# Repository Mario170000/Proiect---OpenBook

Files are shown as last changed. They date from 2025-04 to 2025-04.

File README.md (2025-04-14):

# Proiect---OpenBook
Proiectarea unui e-book reader open book

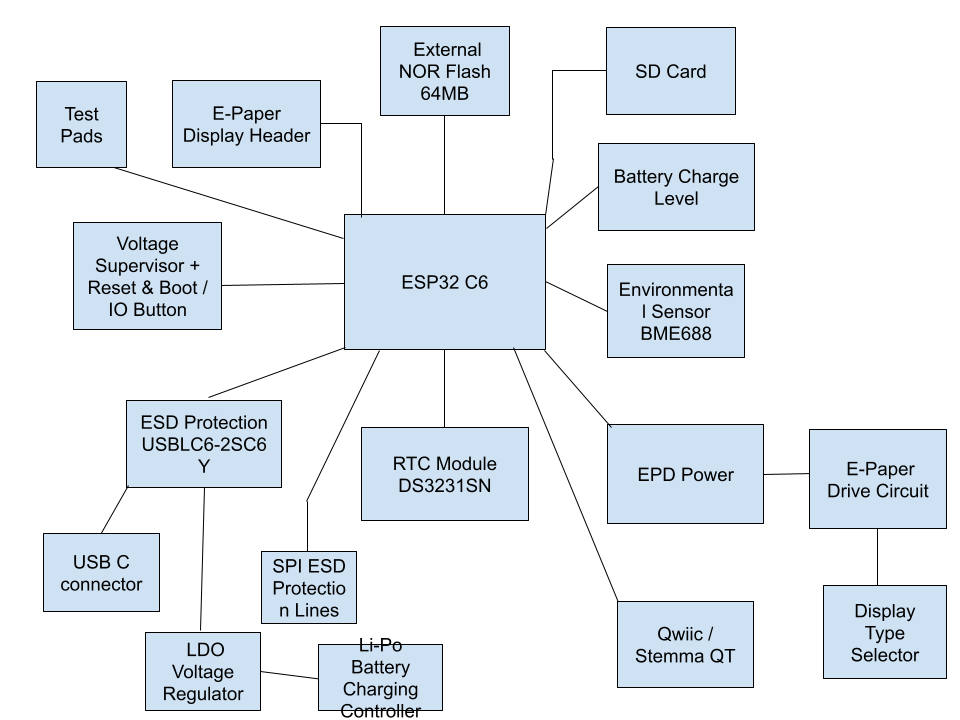
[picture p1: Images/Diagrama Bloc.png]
Diagrama bloc


BOM:

| Qty | Value | Device | Parts | Description | WHERE_TO_BUY | DATASHEET |
|-----|---|---|---|---|---|---|
| 1 | | ADAFRUIT_LEDCHIP-LED0603 | CHG_LED | LED | [link](https://ro.mouser.com/ProductDetail/BJB/35.116.1007-001-01?qs=iLKYxzqNS76jqQb6thkyzg%3D%3D) | [link](https://ro.mouser.com/datasheet/2/904/BJBDE_6680739_v3_Datasheet_35_116_1007_85_Optics4x-3193726.pdf) |
| 3 | | EAGLE-LTSPICE_CC0402 | C4_USB, C5_USB, C17 | CAPACITOR, European symbol | [link](https://ro.mouser.com/ProductDetail/YAGEO/CC0402KRX7R5BB474?qs=tS%2FAHvPQ%2F56tORtAcxAOhQ%3D%3D) | [link](https://ro.mouser.com/datasheet/2/447/UPY_GPHC_X7R_6_3V_to_250V_24-3441574.pdf) |
| 1 | | SJ | SJ1 | SMD solder JUMPER | [link](https://ro.mouser.com/ProductDetail/Amphenol-FCI/71363-302LF?qs=QPQicS5vByJvpVjU0oRgsQ%3D%3D) | [link](https://cdn.amphenol-cs.com/media/wysiwyg/files/documentation/datasheet/boardwiretoboard/bwb_dubox_shunts.pdf) |
| 1 | 0.1uF/50V | EAGLE-LTSPICE_CC0402 | EPD_C5 | CAPACITOR, European symbol | [link](https://ro.mouser.com/ProductDetail/YAGEO/CC0402JRX7R8BB104?qs=tS%2FAHvPQ%2F56C6Jcuby2Lxg%3D%3D) | [link](https://ro.mouser.com/datasheet/2/447/UPY_GPHC_X7R_6_3V_to_250V_24-3441574.pdf) |
| 1 | 0.47 | ESP32_WROVER_EAGLE-LTSPICE_RR0402 | R4 | RESISTOR, European symbol | [link](https://ro.mouser.com/ProductDetail/Vishay/PFRR0402Y2101WBT?qs=iLKYxzqNS75ICTUqzuuuLQ%3D%3D) | [link](https://www.vishay.com/doc?53046) |
| 1 | 100K | ESP32_WROVER_EAGLE-LTSPICE_RR0402 | R1_PWRUSB | RESISTOR, European symbol | [link](https://ro.mouser.com/ProductDetail/Vishay/PFRR0402Y1003WBT?qs=iLKYxzqNS76UwFIGpGXUcw%3D%3D) | [link](https://www.vishay.com/doc?53046) |
| 7 | 100nF | EAGLE-LTSPICE_CC0402 | C1, C2, C6, C8, C9, C10, C_DELAY | CAPACITOR, European symbol | [link](https://ro.mouser.com/ProductDetail/YAGEO/CC0402KRX7R5BB474?qs=tS%2FAHvPQ%2F56tORtAcxAOhQ%3D%3D) | [link](https://ro.mouser.com/datasheet/2/447/UPY_GPHC_X7R_6_3V_to_250V_24-3441574.pdf) |
| 1 | 100uF | RCL_CPOL-EUCT3528 | C3 | POLARIZED CAPACITOR, European symbol | [link](https://ro.mouser.com/ProductDetail/Panasonic/EEU-FS1K101L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) | [link](https://www.mouser.com/catalog/specsheets/Panasonic_08082018_Capacitor%20Radial%20Leaded%20Lytic%20(EEU-FS)%20020118.pdf) |
| 12  | 10K | ESP32_WROVER_EAGLE-LTSPICE_RR0402 | R1_PINH, R1_PINH1, R2-PINH1, R2_PINH, R3, R5, R6, R7, R8, R9, R10, R_CL1 | RESISTOR, European symbol | [link](https://ro.mouser.com/ProductDetail/Vishay/PFRR0402Y1002WBT?qs=iLKYxzqNS75QPApzdnOraw%3D%3D) | [link](https://www.vishay.com/doc?53046) |
| 3 | 10k | ESP32_WROVER_EAGLE-LTSPICE_RR0402 | R_BOOT, R_CHANGE, R_RESET | RESISTOR, European symbol | [link](https://ro.mouser.com/ProductDetail/Vishay/PFRR0402Y1002WBT?qs=iLKYxzqNS75QPApzdnOraw%3D%3D) | [link](https://www.vishay.com/doc?53046) |
| 1 | 10uF | EAGLE-LTSPICE_CC0402 | C7 | CAPACITOR, European symbol | [link](https://ro.mouser.com/ProductDetail/YAGEO/CC0402MRX5R4BB106?qs=tS%2FAHvPQ%2F561gTjBOiVihQ%3D%3D) | [link](https://ro.mouser.com/datasheet/2/447/upy_gphc_x5r_4v_to_50v-3461255.pdf) |
| 1 | 112A-TAAR-R03_ATTEND | 112A-TAAR-R03_ATTEND | J4 | Micro SD Card Socket, Push-Push Type, Top Mount, SMT, H=1.83mm, 10u | [link](https://ro.mouser.com/ProductDetail/Swissbit/SFSD256GL2AM1TO-E-8H-231-STD?qs=%252BXxaIXUDbq3EiR9fdqsT0g%3D%3D) | [link](https://ro.mouser.com/datasheet/2/615/Swissbit_02_03_2025_S_50_data_sheet-3561244.pdf) |
| 1 | 15 | ESP32_WROVER_EAGLE-LTSPICE_RR0402 | R_CAPACITOR | RESISTOR, European symbol | [link](https://ro.mouser.com/ProductDetail/Vishay/PFRR0402Y1002WBT?qs=iLKYxzqNS75QPApzdnOraw%3D%3D) | [link](https://www.vishay.com/doc?53046) |
| 1 | 1uF | EAGLE-LTSPICE_CC0402 | C5 | CAPACITOR, European symbol | [link](https://ro.mouser.com/ProductDetail/YAGEO/CC0402KPX7R9BB332?qs=tS%2FAHvPQ%2F56Ev%2FR70%252BDkow%3D%3D) | [link](https://ro.mouser.com/datasheet/2/447/UPY_GPHC_X7R_6_3V_to_250V_24-3441574.pdf) |
| 9 | 1uF/50V | EAGLE-LTSPICE_CC0402 | EPD_C1, EPD_C2, EPD_C6, EPD_C7, EPD_C8, EPD_C9, EPD_C10, EPD_C11, EPD_C12 | CAPACITOR, European symbol | [link](https://ro.mouser.com/ProductDetail/YAGEO/CC0402KPX7R9BB332?qs=tS%2FAHvPQ%2F56Ev%2FR70%252BDkow%3D%3D) | [link](https://ro.mouser.com/datasheet/2/447/UPY_GPHC_X7R_6_3V_to_250V_24-3441574.pdf) |
| 1 | 2.2 | ESP32_WROVER_EAGLE-LTSPICE_RR0402 | R2 | RESISTOR, European symbol | [link](https://ro.mouser.com/ProductDetail/Vishay/PFRR0402Y2201WBT?qs=iLKYxzqNS76BFrJRYiyDBw%3D%3D) | [link](https://www.vishay.com/doc?53046) |
| 1 | 200 | ESP32_WROVER_EAGLE-LTSPICE_RR0402 | R1_BAT | RESISTOR, European symbol | [link](https://ro.mouser.com/ProductDetail/Vishay/PFRR0402Y2101WBT?qs=iLKYxzqNS75ICTUqzuuuLQ%3D%3D) | [link](https://www.vishay.com/doc?53046) |
| 2 | 20V/4.2A/52mO/1.4W | ESP32_WROVER_SPARKFUN-DISCRETESEMI_MOSFET_PCH-DMG2305UX-7 | Q1, Q2 | P-channel MOSFETs | [link](https://ro.mouser.com/ProductDetail/Diodes-Incorporated/DMG2305UX-7?qs=L1DZKBg7t5F%2FNBHrjfxC%252Bg%3D%3D) | [link](https://www.diodes.com/assets/Datasheets/DMG2305UX.pdf) |
| 2 | 2K | ESP32_WROVER_EAGLE-LTSPICE_RR0402 | R1, R2_BAT | RESISTOR, European symbol | [link](https://ro.mouser.com/ProductDetail/Vishay/PFRR0402Y2001WBT?qs=iLKYxzqNS75yWwLpEkqbdw%3D%3D) | [link](https://www.vishay.com/doc?53046) |
| 4 | 4.7uF | EAGLE-LTSPICE_CC0402 | C1_BAT, C1_BAT2, C2_BAT, C4 | CAPACITOR, European symbol | [link](https://ro.mouser.com/ProductDetail/YAGEO/CC0402KRX5R6BB105?qs=BKNoF%2F0xMNu0TvpE6ze2Iw%3D%3D) | [link](https://ro.mouser.com/datasheet/2/447/upy_gphc_x5r_4v_to_50v-3461255.pdf) |
| 1 | 5K1 | ESP32_WROVER_EAGLE-LTSPICE_RR0402 | R2-USB1 | RESISTOR, European symbol | [link](https://ro.mouser.com/ProductDetail/Vishay/PFRR0402E4752BBT?qs=%252BXxaIXUDbq1vDshWgSXpwA%3D%3D) | [link](https://www.vishay.com/doc?53046) |
| 1 | 5k1 | ESP32_WROVER_EAGLE-LTSPICE_RR0402 | R2-USB | RESISTOR, European symbol | [link](https://ro.mouser.com/ProductDetail/Vishay/PFRR0402E4752BBT?qs=%252BXxaIXUDbq1vDshWgSXpwA%3D%3D) | [link](https://www.vishay.com/doc?53046) |
| 1 | 68uH | 744043680IND_4828-WE-TPC_WRE | L1 | | [link](https://ro.mouser.com/ProductDetail/Wurth-Elektronik/744043680?qs=PGXP4M47uW6VkZq%252BkzjrHA%3D%3D) | [link](https://www.we-online.com/components/products/datasheet/744043680.pdf) |
| 1 | BD5229G-TR | BD5229G-TR | IC1 | Voltage Detector with Adjustable Delay Time: CMOS processes are utilized to develop high precision, low current consumption CMOS reset ICs that allow arbitrary setting of the delay time. | [link](https://ro.mouser.com/ProductDetail/ROHM-Semiconductor/BD5229G-TR?qs=4kLU8WoGk0vvnhrrYwdszw%3D%3D) | [link](https://fscdn.rohm.com/en/products/databook/datasheet/ic/power/voltage_detector/bd52xxg-e.pdf) |
| 3 | BUTTON_CUSYOMV1 | BUTTON_CUSYOMV1 | BOOT_BUTTON, CHANGE_BUTTON, RESET_BUTTON | | [link](https://ro.mouser.com/ProductDetail/Bulgin/C7003SABR7?qs=5aG0NVq1C4zkqomKc3HwTQ%3D%3D) | [link](https://www.bulgin.com/products/pub/media/bulgin/data/A_Push%20button.pdf) |
| 1 | CPH3225A | CPH3225A | C10_SUPERCAP | Cap 0.011F 3.3V 1210 Flat Check availability | [link](https://ro.mouser.com/ProductDetail/Seiko-Semiconductors/CPH3225A?qs=3etwrb1wR%252BhUOph6lAO7eg%3D%3D) | [link](https://ro.mouser.com/datasheet/2/360/Seiko_Instruments_MicroBattery_E_20230330_2024Jan_-3561061.pdf) |
| 1 | DS3231SN# | DS3231SN# | U3 | Real Time Clock Serial 16-Pin SOIC W T/R Check availability | [link](https://ro.mouser.com/ProductDetail/Analog-Devices-Maxim-Integrated/DS3231SN?qs=1eQvB6Dk1vhUlr8%2FOrV0Fw%3D%3D) | [link](https://ro.mouser.com/datasheet/2/609/DS3231-3421123.pdf) |
| 1 | ESP32-C6-WROOM-1-N8 | ESP32-C6-WROOM-1-N8 | U2 | Check availability | [link](https://ro.mouser.com/ProductDetail/Espressif-Systems/ESP32-C6-WROOM-1-N8?qs=8Wlm6%252BaMh8ST02Gmwp74cw%3D%3D) | [link](https://ro.mouser.com/datasheet/2/891/Espressif_ESP32_C6_WROOM_1__Datasheet_V0_1_PRELIMI-3239987.pdf) |
| 1 | ESP32C6_VARISTORCN1812 | ESP32C6_VARISTORCN1812 | PFMP.050.1 | VARISTOR | [link](https://ro.mouser.com/ProductDetail/EPCOS-TDK/B72580V3140S272?qs=v4Mlc8l4PHkyDvCWZ8i%252Bvg%3D%3D) | [link](https://en.tdk.eu/inf/75/db/CTVS_14/Surge_protection_series.pdf) |
| 2 | ESP32_WROVER_AVX---SD0805S020S1R0_AVX_SD0805S020S1R0_0_0AVX_SD0805S020S1R0_0_0 | ESP32_WROVER_AVX---SD0805S020S1R0_AVX_SD0805S020S

## ESP32-C6 Pinout

| Pin | Name | Function |
|-----|---|---|
| 1 | GND | Common ground |
| 2 | 3V3 | Power line |
| 3 | RESET | Reset button |
| 4 | SS_SD | SD card chip select |
| 5 | EPD_DC | E-Paper Display Data/Command |
| 6 | SCK | SPI Clock for BME688 |
| 7 | MOSI | SPI Master Out Slave In |
| 8 | INT_RTC | RTC Interrupt (DS3231SN) |
| 9 | 32KHZ | RTC 32kHz output |
| 10  | 3V3/GPIO8 | Power line |
| 11  | EPD_CS | E-Paper Display Chip Select |
| 12  | FLASH_CS | External NOR Flash (64MB) |
| 13  | USB_D- | USB D- line |
| 14  | USB_D+ | USB D+ line |
| 15  | IO/BOOT | BOOT button |
| 16  | RTC_RST | RTC Module Reset (DS3231SN) |
| 17  | I2C_PW | BME688 power line |
| 18  | EPD_3V3_C | EPD Power |
| 19  | SDA | Battery charge level (I²C) |
| 20  | SCL | Battery SCL (I²C) |
| 21  | EPD_RST | E-Paper Display Reset |
| 22  | X | Not in use |
| 23  | IO/CHANGE | User button |
| 24  | RX | UART RX for debugging |
| 25  | TX | UART TX for debugging |
| 26  | EPD_BUSY | E-Paper Display Busy signal |
| 27  | MISO | SPI Master In Slave Out |

# Hardware Components Overview

This section provides a detailed description of the key hardware components used in the OpenBook project.

## ESP32-C6-WROOM-1-N8
The **ESP32-C6-WROOM-1-N8** is a powerful Wi-Fi 6 and Bluetooth 5 LE module based on the ESP32-C6 SoC, with 8MB of integrated flash. It features a RISC-V processor and provides low-power connectivity for IoT applications. In this project, it acts as the **main microcontroller**, handling data acquisition, processing, and wireless communication.

## BME680
The **BME680** is a 4-in-1 environmental sensor that measures **temperature, humidity, barometric pressure, and air quality (VOC)**. It communicates via I²C or SPI. In this device, it provides ambient condition monitoring, enabling features like smart display behavior or indoor air quality feedback.

## MCP73831T-2ACI/OT
The **MCP73831** is a **Li-Ion/Li-Po linear battery charger** IC, supporting single-cell charging through a constant-current/constant-voltage algorithm. It is used to safely charge the onboard Li-Po battery when the device is connected to USB power.

## W25Q512JVEIQ
The **W25Q512JVEIQ** is a **512M-bit (64MB) SPI NOR Flash memory** from Winbond. It provides additional non-volatile storage space, useful for storing large assets such as e-books, sensor logs, or firmware updates. It is connected via SPI to the ESP32.

## USBLC6-2SC6Y
The **USBLC6-2SC6Y** is a **dual-line ESD protection device** designed to protect USB data lines from electrostatic discharge. It ensures signal integrity and protects the USB interface (D+ and D−) from damage, especially during hot-plug events or electrostatic contact.

## 112A-TAAR-R03
The **112A-TAAR-R03** is a **mechanical tactile push button switch**, typically used for user input. In this project, it serves as a **physical interface**, such as page turning, menu selection, or device wake-up. It is connected to GPIOs on the ESP32 and configured with internal pull-up resistors.

## USB4110-GF-A
The **USB4110-GF-A** is a **USB Type-C receptacle connector**. It provides the physical interface for USB charging and communication. It connects to the USB-to-UART circuitry (or directly to ESP32 if used in native USB mode) and to the battery charging IC.

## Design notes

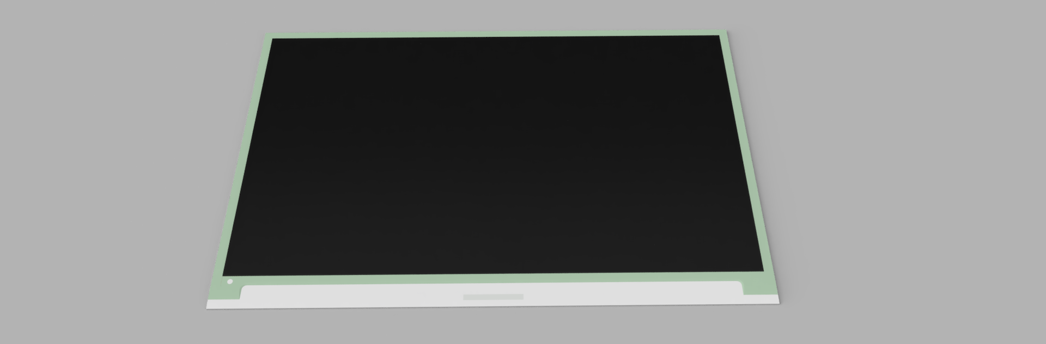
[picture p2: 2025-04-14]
Images/Display-OpenBook.PNG

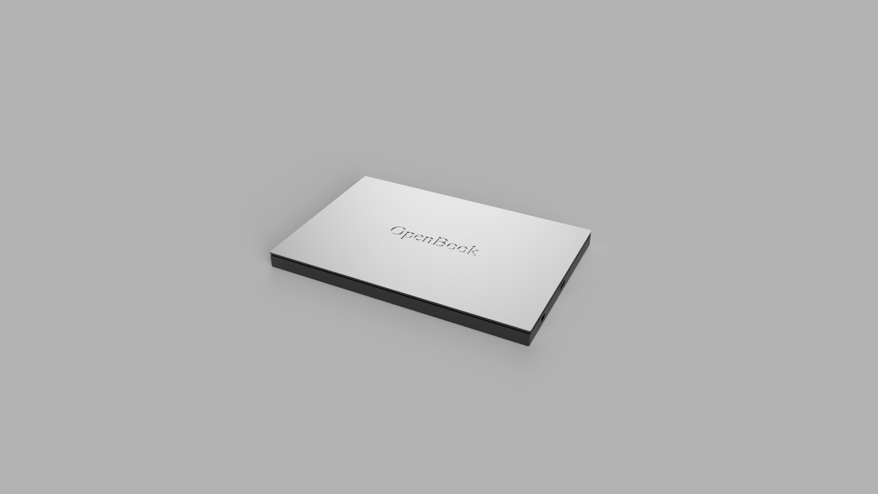
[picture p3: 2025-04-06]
Images/OpenBook-1.png

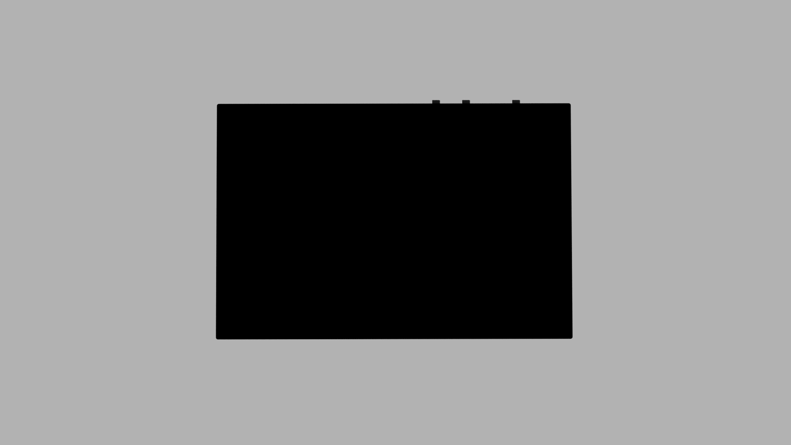
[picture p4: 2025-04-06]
Images/OpenBook-3.png

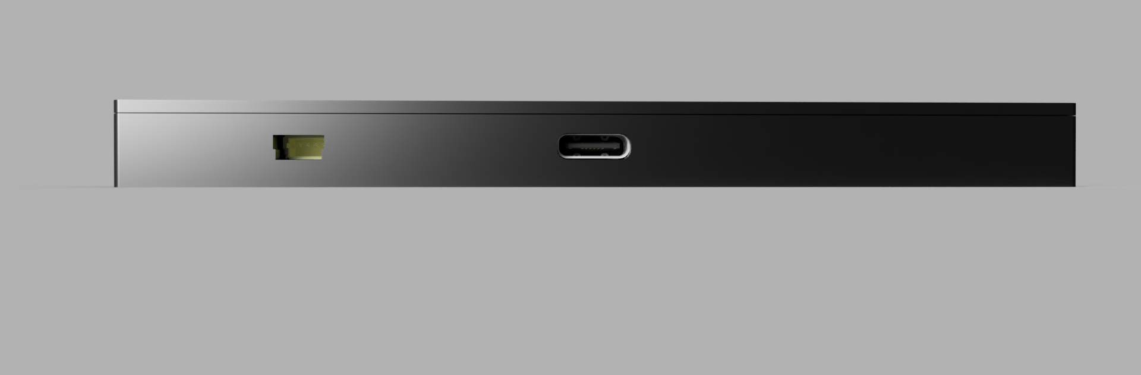
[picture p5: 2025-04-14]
Images/Ports_OpenBook.PNG

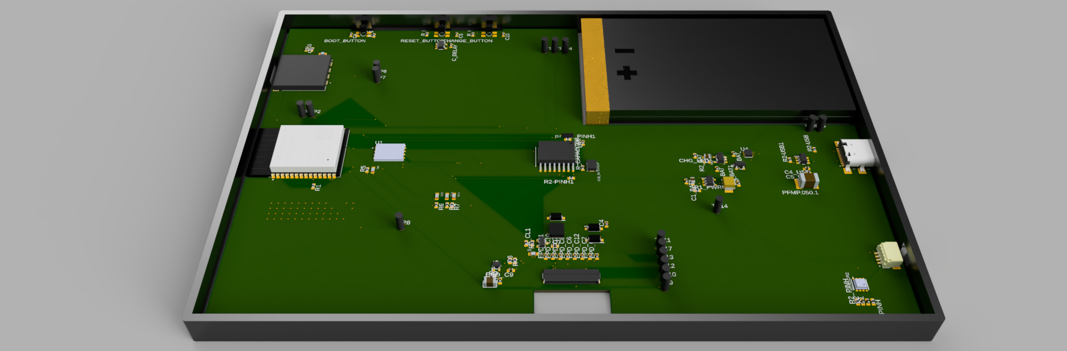
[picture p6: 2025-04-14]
Images/PCB_OpenBook.PNG

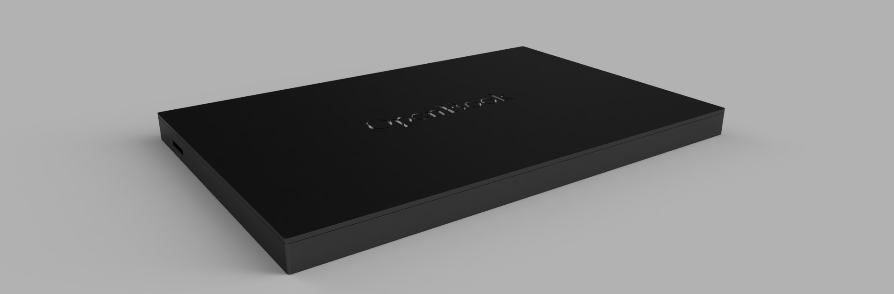
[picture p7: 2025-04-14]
Images/SideView_OpenBook.png

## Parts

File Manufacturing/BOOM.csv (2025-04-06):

Qty | Value | Device | Parts | Description | WHERE_TO_BUY | DATASHEET
1 |  | ADAFRUIT_LEDCHIP-LED0603 | CHG_LED | LED | https://ro.mouser.com/ProductDetail/BJB/35.116.1007-001-01?qs=iLKYxzqNS76jqQb6thkyzg%3D%3D | https://ro.mouser.com/datasheet/2/904/BJBDE_6680739_v3_Datasheet_35_116_1007_85_Optics4x-3193726.pdf
3 |  | EAGLE-LTSPICE_CC0402 | C4_USB, C5_USB, C17 | CAPACITOR, European symbol | https://ro.mouser.com/ProductDetail/YAGEO/CC0402KRX7R5BB474?qs=tS%2FAHvPQ%2F56tORtAcxAOhQ%3D%3D | https://ro.mouser.com/datasheet/2/447/UPY_GPHC_X7R_6_3V_to_250V_24-3441574.pdf
1 |  | SJ | SJ1 | SMD solder JUMPER | https://ro.mouser.com/ProductDetail/Amphenol-FCI/71363-302LF?qs=QPQicS5vByJvpVjU0oRgsQ%3D%3D | https://cdn.amphenol-cs.com/media/wysiwyg/files/documentation/datasheet/boardwiretoboard/bwb_dubox_shunts.pdf
1 | 0.1uF/50V | EAGLE-LTSPICE_CC0402 | EPD_C5 | CAPACITOR, European symbol | https://ro.mouser.com/ProductDetail/YAGEO/CC0402JRX7R8BB104?qs=tS%2FAHvPQ%2F56C6Jcuby2Lxg%3D%3D | https://ro.mouser.com/datasheet/2/447/UPY_GPHC_X7R_6_3V_to_250V_24-3441574.pdf
1 | 0.47 | ESP32_WROVER_EAGLE-LTSPICE_RR0402 | R4 | RESISTOR, European symbol | https://ro.mouser.com/ProductDetail/Vishay/PFRR0402Y2101WBT?qs=iLKYxzqNS75ICTUqzuuuLQ%3D%3D | https://www.vishay.com/doc?53046
1 | 100K | ESP32_WROVER_EAGLE-LTSPICE_RR0402 | R1_PWRUSB | RESISTOR, European symbol | https://ro.mouser.com/ProductDetail/Vishay/PFRR0402Y1003WBT?qs=iLKYxzqNS76UwFIGpGXUcw%3D%3D | https://www.vishay.com/doc?53046
7 | 100nF | EAGLE-LTSPICE_CC0402 | C1, C2, C6, C8, C9, C10, C_DELAY | CAPACITOR, European symbol | https://ro.mouser.com/ProductDetail/YAGEO/CC0402KRX7R5BB474?qs=tS%2FAHvPQ%2F56tORtAcxAOhQ%3D%3D | https://ro.mouser.com/datasheet/2/447/UPY_GPHC_X7R_6_3V_to_250V_24-3441574.pdf
1 | 100uF | RCL_CPOL-EUCT3528 | C3 | POLARIZED CAPACITOR, European symbol | https://ro.mouser.com/ProductDetail/Panasonic/EEU-FS1K101L | https://www.mouser.com/catalog/specsheets/Panasonic_08082018_Capacitor%20Radial%20Leaded%20Lytic%20(EEU-FS)%20020118.pdf
12 | 10K | ESP32_WROVER_EAGLE-LTSPICE_RR0402 | R1_PINH, R1_PINH1, R2-PINH1, R2_PINH, R3, R5, R6, R7, R8, R9, R10, R_CL1 | RESISTOR, European symbol | https://ro.mouser.com/ProductDetail/Vishay/PFRR0402Y1002WBT?qs=iLKYxzqNS75QPApzdnOraw%3D%3D | https://www.vishay.com/doc?53046
3 | 10k | ESP32_WROVER_EAGLE-LTSPICE_RR0402 | R_BOOT, R_CHANGE, R_RESET | RESISTOR, European symbol | https://ro.mouser.com/ProductDetail/Vishay/PFRR0402Y1002WBT?qs=iLKYxzqNS75QPApzdnOraw%3D%3D | https://www.vishay.com/doc?53046
1 | 10uF | EAGLE-LTSPICE_CC0402 | C7 | CAPACITOR, European symbol | https://ro.mouser.com/ProductDetail/YAGEO/CC0402MRX5R4BB106?qs=tS%2FAHvPQ%2F561gTjBOiVihQ%3D%3D | https://ro.mouser.com/datasheet/2/447/upy_gphc_x5r_4v_to_50v-3461255.pdf
1 | 112A-TAAR-R03_ATTEND | 112A-TAAR-R03_ATTEND | J4 | Micro SD Card Socket, Push-Push Type, Top Mount, SMT, H=1.83mm, 10u | https://ro.mouser.com/ProductDetail/Swissbit/SFSD256GL2AM1TO-E-8H-231-STD?qs=%252BXxaIXUDbq3EiR9fdqsT0g%3D%3D | https://ro.mouser.com/datasheet/2/615/Swissbit_02_03_2025_S_50_data_sheet-3561244.pdf
1 | 15 | ESP32_WROVER_EAGLE-LTSPICE_RR0402 | R_CAPACITOR | RESISTOR, European symbol | https://ro.mouser.com/ProductDetail/Vishay/PFRR0402Y1002WBT?qs=iLKYxzqNS75QPApzdnOraw%3D%3D | https://www.vishay.com/doc?53046
1 | 1uF | EAGLE-LTSPICE_CC0402 | C5 | CAPACITOR, European symbol | https://ro.mouser.com/ProductDetail/YAGEO/CC0402KPX7R9BB332?qs=tS%2FAHvPQ%2F56Ev%2FR70%252BDkow%3D%3D | https://ro.mouser.com/datasheet/2/447/UPY_GPHC_X7R_6_3V_to_250V_24-3441574.pdf
9 | 1uF/50V | EAGLE-LTSPICE_CC0402 | EPD_C1, EPD_C2, EPD_C6, EPD_C7, EPD_C8, EPD_C9, EPD_C10, EPD_C11, EPD_C12 | CAPACITOR, European symbol | https://ro.mouser.com/ProductDetail/YAGEO/CC0402KPX7R9BB332?qs=tS%2FAHvPQ%2F56Ev%2FR70%252BDkow%3D%3D | https://ro.mouser.com/datasheet/2/447/UPY_GPHC_X7R_6_3V_to_250V_24-3441574.pdf
1 | 2.2 | ESP32_WROVER_EAGLE-LTSPICE_RR0402 | R2 | RESISTOR, European symbol | https://ro.mouser.com/ProductDetail/Vishay/PFRR0402Y2201WBT?qs=iLKYxzqNS76BFrJRYiyDBw%3D%3D | https://www.vishay.com/doc?53046
1 | 200 | ESP32_WROVER_EAGLE-LTSPICE_RR0402 | R1_BAT | RESISTOR, European symbol | https://ro.mouser.com/ProductDetail/Vishay/PFRR0402Y2101WBT?qs=iLKYxzqNS75ICTUqzuuuLQ%3D%3D | https://www.vishay.com/doc?53046
2 | 20V/4.2A/52mO/1.4W | ESP32_WROVER_SPARKFUN-DISCRETESEMI_MOSFET_PCH-DMG2305UX-7 | Q1, Q2 | P-channel MOSFETs | https://ro.mouser.com/ProductDetail/Diodes-Incorporated/DMG2305UX-7?qs=L1DZKBg7t5F%2FNBHrjfxC%252Bg%3D%3D | https://www.diodes.com/assets/Datasheets/DMG2305UX.pdf
2 | 2K | ESP32_WROVER_EAGLE-LTSPICE_RR0402 | R1, R2_BAT | RESISTOR, European symbol | https://ro.mouser.com/ProductDetail/Vishay/PFRR0402Y2001WBT?qs=iLKYxzqNS75yWwLpEkqbdw%3D%3D | https://www.vishay.com/doc?53046
4 | 4.7uF | EAGLE-LTSPICE_CC0402 | C1_BAT, C1_BAT2, C2_BAT, C4 | CAPACITOR, European symbol | https://ro.mouser.com/ProductDetail/YAGEO/CC0402KRX5R6BB105?qs=BKNoF%2F0xMNu0TvpE6ze2Iw%3D%3D | https://ro.mouser.com/datasheet/2/447/upy_gphc_x5r_4v_to_50v-3461255.pdf
1 | 5K1 | ESP32_WROVER_EAGLE-LTSPICE_RR0402 | R2-USB1 | RESISTOR, European symbol | https://ro.mouser.com/ProductDetail/Vishay/PFRR0402E4752BBT?qs=%252BXxaIXUDbq1vDshWgSXpwA%3D%3D | https://www.vishay.com/doc?53046
1 | 5k1 | ESP32_WROVER_EAGLE-LTSPICE_RR0402 | R2-USB | RESISTOR, European symbol | https://ro.mouser.com/ProductDetail/Vishay/PFRR0402E4752BBT?qs=%252BXxaIXUDbq1vDshWgSXpwA%3D%3D | https://www.vishay.com/doc?53046
1 | 68uH | 744043680IND_4828-WE-TPC_WRE | L1 |  | https://ro.mouser.com/ProductDetail/Wurth-Elektronik/744043680?qs=PGXP4M47uW6VkZq%252BkzjrHA%3D%3D | https://www.we-online.com/components/products/datasheet/744043680.pdf
1 | BD5229G-TR | BD5229G-TR | IC1 | Voltage Detector with Adjustable Delay Time: CMOS processes are utilized to develop high precision, low current consumption CMOS reset ICs that allow arbitrary setting of the delay time. The extensive lineup includes both Nch Open Drain and CMOS output types in a wide range of detection voltages (from 2.3V to 6.0V, in 0.1V steps), enabling selection of the ideal solution based on customer requirements. In addition, the entire series is of course both lead-free and RoHS-compliant. | https://ro.mouser.com/ProductDetail/ROHM-Semiconductor/BD5229G-TR?qs=4kLU8WoGk0vvnhrrYwdszw%3D%3D | https://fscdn.rohm.com/en/products/databook/datasheet/ic/power/voltage_detector/bd52xxg-e.pdf
3 | BUTTON_CUSYOMV1 | BUTTON_CUSYOMV1 | BOOT_BUTTON, CHANGE_BUTTON, RESET_BUTTON |  | https://ro.mouser.com/ProductDetail/Bulgin/C7003SABR7?qs=5aG0NVq1C4zkqomKc3HwTQ%3D%3D | https://www.bulgin.com/products/pub/media/bulgin/data/A_Push%20button.pdf
1 | CPH3225A | CPH3225A | C10_SUPERCAP | Cap 0.011F 3.3V 1210 Flat Check availability | https://ro.mouser.com/ProductDetail/Seiko-Semiconductors/CPH3225A?qs=3etwrb1wR%252BhUOph6lAO7eg%3D%3D | https://ro.mouser.com/datasheet/2/360/Seiko_Instruments_MicroBattery_E_20230330_2024Jan_-3561061.pdf
1 | DS3231SN# | DS3231SN# | U3 | Real Time Clock Serial 16-Pin SOIC W T/R Check availability | https://ro.mouser.com/ProductDetail/Analog-Devices-Maxim-Integrated/DS3231SN?qs=1eQvB6Dk1vhUlr8%2FOrV0Fw%3D%3D | https://ro.mouser.com/datasheet/2/609/DS3231-3421123.pdf
1 | ESP32-C6-WROOM-1-N8 | ESP32-C6-WROOM-1-N8 | U2 | Check availability | https://ro.mouser.com/ProductDetail/Espressif-Systems/ESP32-C6-WROOM-1-N8?qs=8Wlm6%252BaMh8ST02Gmwp74cw%3D%3D | https://ro.mouser.com/datasheet/2/891/Espressif_ESP32_C6_WROOM_1__Datasheet_V0_1_PRELIMI-3239987.pdf
1 | ESP32C6_VARISTORCN1812 | ESP32C6_VARISTORCN1812 | PFMP.050.1 | VARISTOR | https://ro.mouser.com/ProductDetail/EPCOS-TDK/B72580V3140S272?qs=v4Mlc8l4PHkyDvCWZ8i%252Bvg%3D%3D | https://en.tdk.eu/inf/75/db/CTVS_14/Surge_protection_series.pdf
2 | ESP32_WROVER_AVX---SD0805S020S1R0_AVX_SD0805S020S1R0_0_0AVX_SD0805S020S1R0_0_0 | ESP32_WROVER_AVX---SD0805S020S1R0_AVX_SD0805S020S1R0_0_0AVX_SD0805S020S1R0_0_0 | D2, D7 | Schottky Barrier Rectifier Diode | https://ro.mouser.com/ProductDetail/KYOCERA-AVX/SD0805S020S1R0?qs=jCA%252BPfw4LHbpkAoSnwrdjw%3D%3D | https://ro.mouser.com/datasheet/2/40/schottky-3165252.pdf
1 | ESP32_WROVER_BME680_BME680 | ESP32_WROVER_BME680_BME680 | SENSOR2 | Integrated Environmental Unit | https://ro.mouser.com/ProductDetail/Bosch-Sensortec/BME680?qs=v271MhAjFHjo0yA%2FC4OnDQ%3D%3D | https://ro.mouser.com/datasheet/2/783/BST_BME680_DS001-1509608.pdf
1 | ESP32_WROVER_SPARKFUN-IC-POWER_MCP73831 | ESP32_WROVER_SPARKFUN-IC-POWER_MCP73831 | MCP73831 | MCP73831T Li-Ion, Li-Pol Controller | https://ro.mouser.com/ProductDetail/Microchip-Technology/MCP73831T-2ACI-OT?qs=yUQqVecv4qvbBQBGbHx0Mw%3D%3D | https://ro.mouser.com/datasheet/2/268/MCP73831_Family_Data_Sheet_DS20001984H-3441711.pdf
1 | FH34SRJ-24S-0.5SH_99_ | FH34SRJ-24S-0.5SH_99_ | J1 | (0.50mm) Surface Mount, Right Angle | https://ro.mouser.com/ProductDetail/Hirose-Connector/FH34SRJ-24S-0.5SH99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 | https://ro.mouser.com/datasheet/2/185/FH34SRJ_24S_0_5SH_99__CL0580_1255_6_99_2DDrawing_0-1615044.pdf
1 | MAX17048G+T10 | MAX17048G+T10 | U4 | Check availability | https://ro.mouser.com/ProductDetail/Analog-Devices-Maxim-Integrated/MAX17048G%2bT10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 | https://ro.mouser.com/datasheet/2/609/MAX17048_MAX17049-3469099.pdf
3 | MBR0530 | MBR0530 | D3, D4, D5 | ON SEMICONDUCTOR - MBR0530 - DIODE, SCHOTTKY, 0.5A, 30V, SOD-123 | https://ro.mouser.com/ProductDetail/onsemi/MBR0530T3G?qs=3JMERSakebpEmdUS6GetdQ%3D%3D | https://www.onsemi.com/PowerSolutions/product.do?id=MBR0530T3G
6 | PGB1010603MR | PGB1010603MR | D6, D8, D9, D10, D11, D12 | Check availability | https://ro.mouser.com/ProductDetail/Littelfuse/PGB1010603MR?qs=gu7KAQ731URLg4GSnNNN7Q%3D%3D | https://www.littelfuse.com/assetdocs/pulseguard-esd-suppressors-pgb1-datasheet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
1 | QWIIC_RIGHT_ANGLE | QWIIC_CONNECTORJS-1MM | J3 | SparkFun I2C Standard Qwiic Connector | https://ro.mouser.com/ProductDetail/Adafruit/4208?qs=PzGy0jfpSMtbScLbr0L5dw%3D%3D | https://ro.mouser.com/manufacturer/adafruit/
1 | SAMACSYS_PARTS_USB4110-GF-A | SAMACSYS_PARTS_USB4110-GF-A | J2 | CONN USB 2.0 TYPE-C R/A SMT | https://ro.mouser.com/ProductDetail/GCT/USB4110-GF-A?qs=KUoIvG%2F9IlYiZvIXQjyJeA%3D%3D | https://ro.mouser.com/datasheet/2/837/GCT_USB4110_Product_Drawing___20k_cycles-3455479.pdf
1 | SI1308EDL-T1-GE3 | SI1308EDL-T1-GE3 | Q3 | MOSFET N-Ch 30V 1.5A TrenchFET SC70 Vishay Si1308EDL-T1-GE3 N-channel MOSFET Transistor, 1.5 A, 30 V, 3-Pin SC-70 | https://ro.mouser.com/ProductDetail/Vishay-Semiconductors/SI1308EDL-T1-GE3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 | https://www.vishay.com/doc?63399
17 | TPTP20R | TPTP20R | TP1, TP2, TP3, TP4, TP5, TP6, TP7, TP8, TP9, TP10, TP11, TP12, TP13, TP14, TP15, TP16, TP17 | Test pad | https://ro.mouser.com/ProductDetail/TE-Connectivity-Holsworthy/RCW-0C?qs=ip69W3eHERVcN99nMRbYaQ%3D%3D | https://ro.mouser.com/datasheet/2/418/4/NG_DS_1773266_A-732548.pdf
1 | USBLC6-2SC6Y | USBLC6-2SC6Y | D1 | Low Cap. ESD Protection Auto SOT-23-6 STMicroelectronics USBLC6-2SC6Y, Dual Uni-Directional TVS Diode Array, 6-Pin SOT-23 | https://ro.mouser.com/ProductDetail/STMicroelectronics/USBLC6-2SC6Y?qs=gNDSiZmRJS%2FOgDexvXkdow%3D%3D | https://ro.mouser.com/datasheet/2/389/usblc6_2sc6y-1852505.pdf
1 | W25Q512JVEIQ | W25Q512JVEIQ | U1 | Check availability | https://ro.mouser.com/ProductDetail/Winbond/W25Q512JVEIQ?qs=l7cgNqFNU1jw6svr3at6tA%3D%3D | https://ro.mouser.com/datasheet/2/949/Winbond_W25Q512JV_Datasheet-3240039.pdf
1 | XC6220A331MR-G | XC6220A331MR-G | IC4 | LDO Voltage Regulators | https://ro.mouser.com/ProductDetail/Torex-Semiconductor/XC6220A331MR-G?qs=AsjdqWjXhJ8ZSWznL1J0gg%3D%3D | https://ro.mouser.com/datasheet/2/760/xc6220-3371556.pdf

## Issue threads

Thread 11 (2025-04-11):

Smd-Line error

anaobreja, 2025-04-11:
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

The component should be placed further inside the board

Closed 2025-04-14.

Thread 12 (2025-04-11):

ESP32 antenna

anaobreja, 2025-04-11:
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

The PCB area under the ESP32 antenna should be cut out to minimize interference with the RF signal!

Closed 2025-04-13.

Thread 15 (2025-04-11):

L1 & U4 footprint errors

anaobreja, 2025-04-11:
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

You should modify the footprint of L1 & U4 to solve Smd - Copper Width errors.

Closed 2025-04-15.

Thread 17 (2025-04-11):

Power traces - vias

anaobreja, 2025-04-11:
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

Power traces are not routed to avoid vias.

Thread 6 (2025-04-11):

EPD_C12 - schematic

anaobreja, 2025-04-11:
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

Replace the net with a new one.

Closed 2025-04-13.

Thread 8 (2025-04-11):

Capacitor value

anaobreja, 2025-04-11:
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

Also, replace the name from C17 to C1_BAT1

Closed 2025-04-13.

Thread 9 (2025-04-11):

GND Plane & Via stiching

anaobreja, 2025-04-11:
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

GND Plane & Via stiching  are missing.

Closed 2025-04-15.

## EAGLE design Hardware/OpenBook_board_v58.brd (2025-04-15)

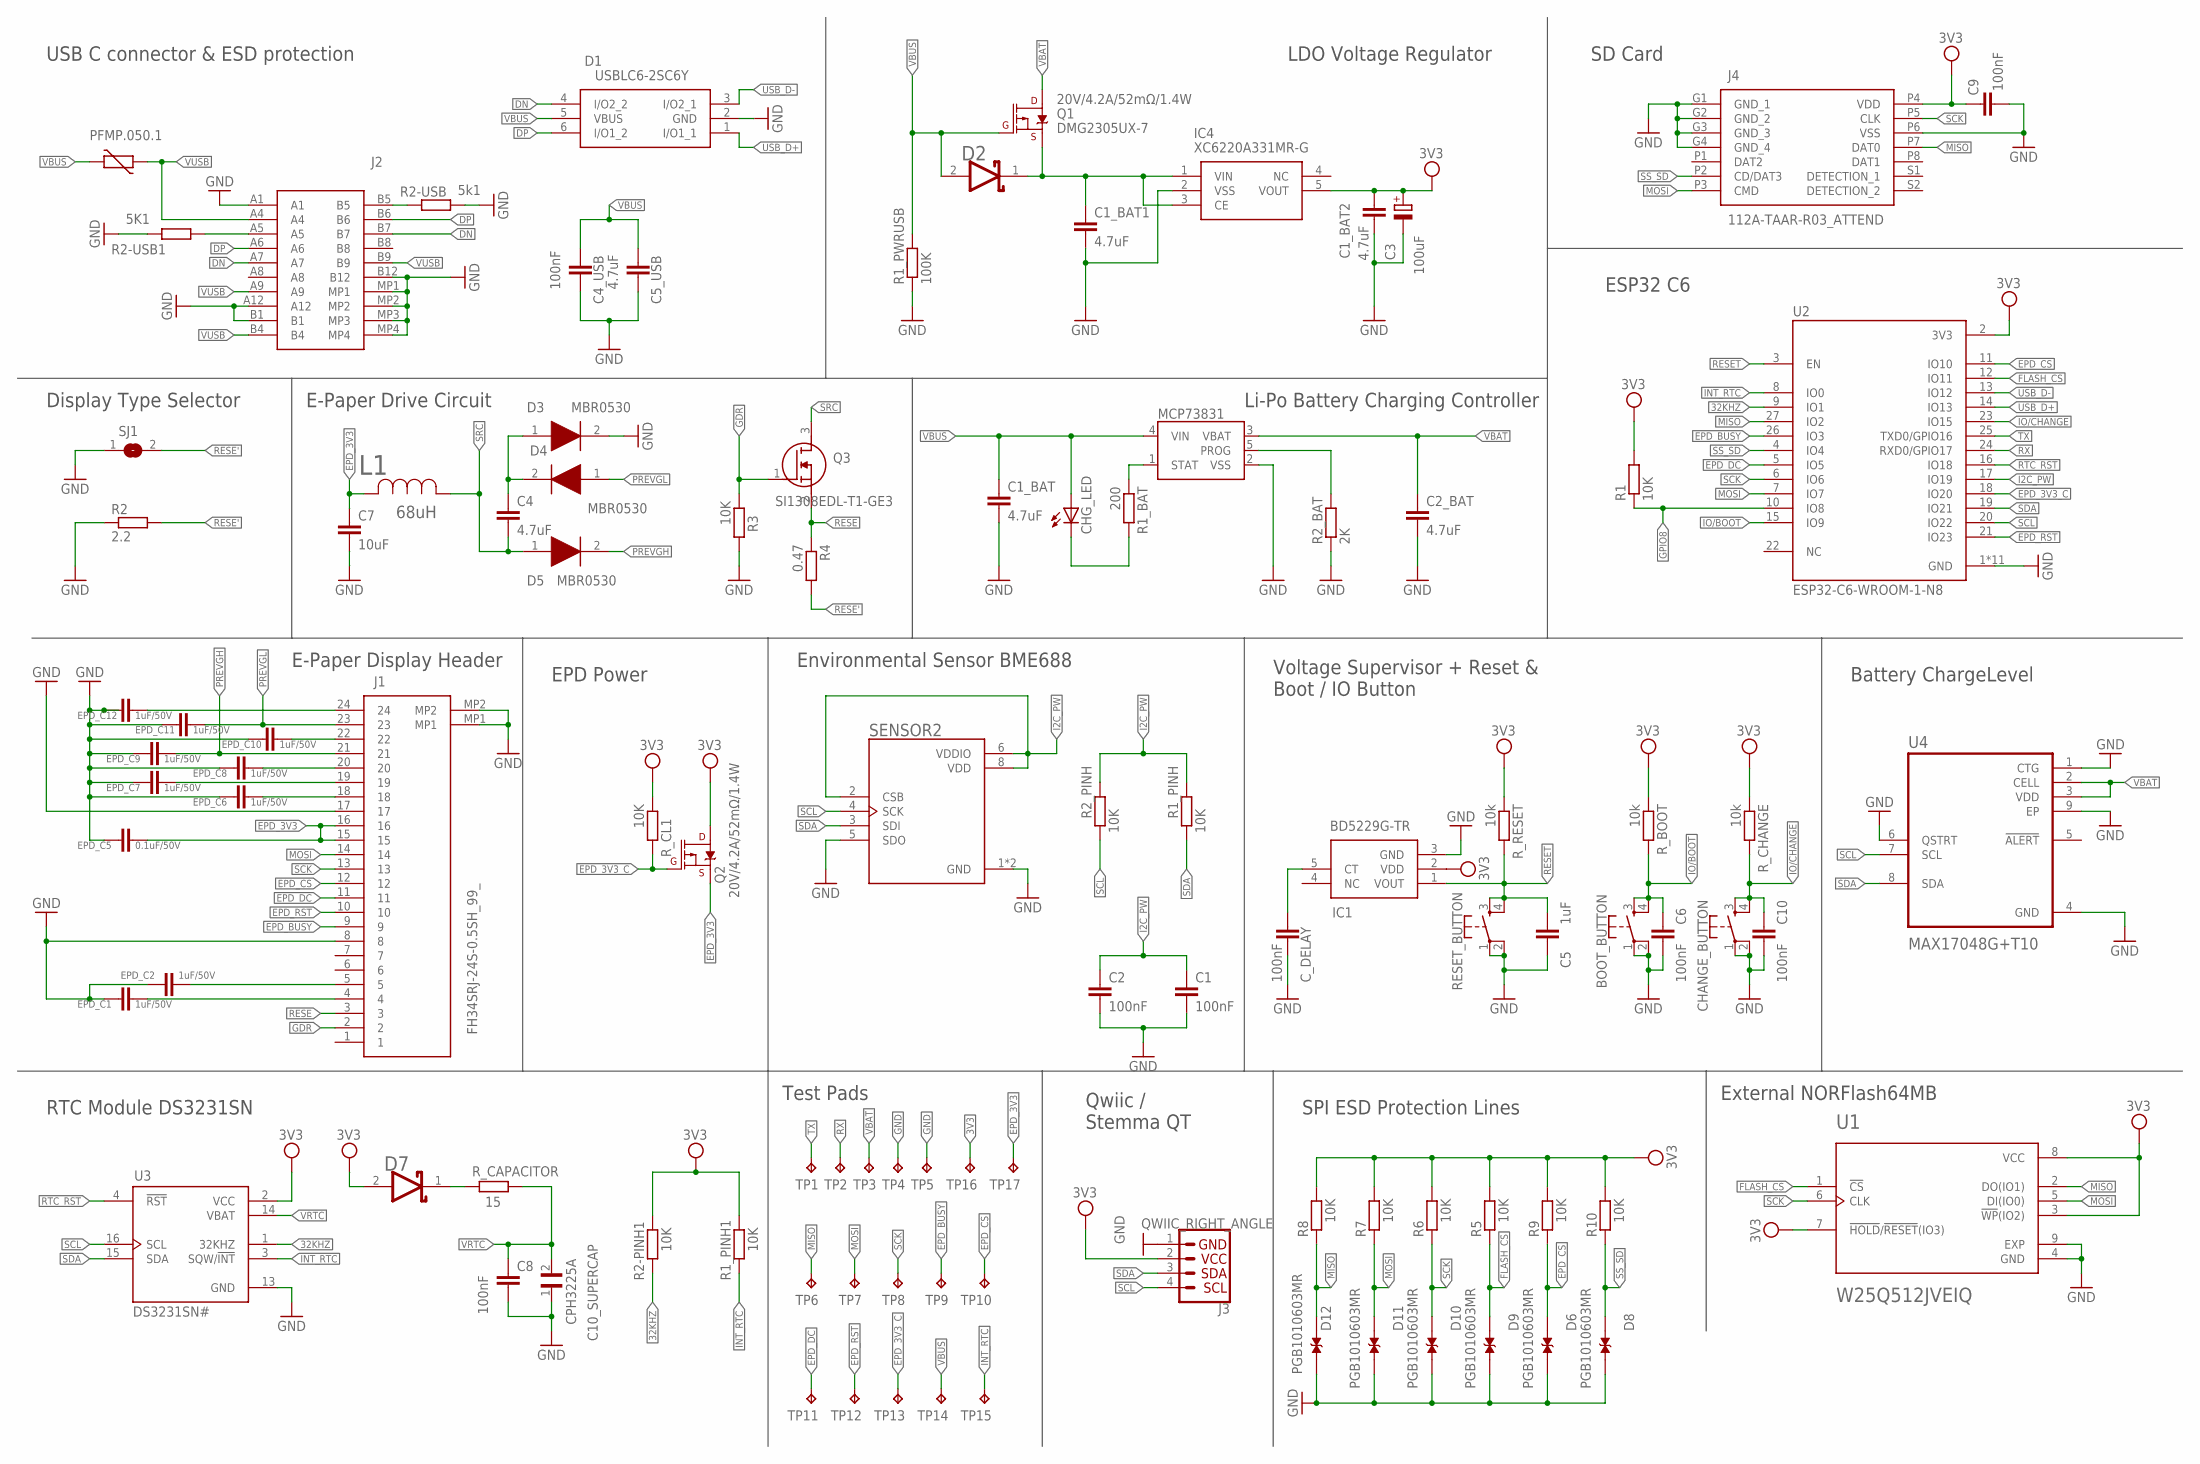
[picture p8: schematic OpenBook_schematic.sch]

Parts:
BOOT_BUTTON: BUTTON_CUSYOMV1; MYBUTTON
C1, C2, C4_USB, C6, C8, C9, C10: 100nF; EAGLE-LTSPICE_C0402
C1_BAT, C1_BAT1, C1_BAT2, C2_BAT, C4, C5_USB: 4.7uF; EAGLE-LTSPICE_C0402
C3: 100uF; RCL_CT3528
C5: 1uF; EAGLE-LTSPICE_C0402
C7: 10uF; EAGLE-LTSPICE_C0402
C10_SUPERCAP: CPH3225A; CAPCP3225X100N
CHANGE_BUTTON: BUTTON_CUSYOMV1; MYBUTTON
CHG_LED: ADAFRUIT_LEDCHIP-LED0603; ADAFRUIT_CHIP-LED0603
C_DELAY: 100nF; EAGLE-LTSPICE_C0402
D1: USBLC6-2SC6Y; SOT95P280X145-6N
D2, D7: ESP32_WROVER_AVX---SD0805S020S1R0_AVX_SD0805S020S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; ESP32_WROVER_AVX---SD0805S020S1R0_AVX_SD0805S020S1R0_0
D3, D4, D5: MBR0530; SOD3716X135N
D6, D8, D9, D10, D11, D12: PGB1010603MR; DIOC1608X36N
EPD_C1, EPD_C2, EPD_C6, EPD_C7, EPD_C8, EPD_C9, EPD_C10, EPD_C11, EPD_C12: 1uF/50V; EAGLE-LTSPICE_C0402
EPD_C5: 0.1uF/50V; EAGLE-LTSPICE_C0402
IC1: BD5229G-TR; SOT95P280X125-5N
IC4: XC6220A331MR-G; SOT95P280X120-5N
J1: FH34SRJ-24S-0.5SH_99_; FH34SRJ24S05SH99
J2: SAMACSYS_PARTS_USB4110-GF-A; SAMACSYS_PARTS_USB4110GFA
J3: QWIIC_RIGHT_ANGLE; JST04_1MM_RA
J4: 112A-TAAR-R03_ATTEND; 112ATAARR03ATTEND
L1: 68uH; IND_4828-WE-TPC_WRE
MCP73831: ESP32_WROVER_SPARKFUN-IC-POWER_MCP73831; ESP32_WROVER_SPARKFUN-IC-POWER_SOT23-5
PFMP.050.1: ESP32C6_VARISTORCN1812; ESP32C6_VARISTOR_CT/CN1812
Q1, Q2: 20V/4.2A/52mΩ/1.4W; ESP32_WROVER_SPARKFUN-DISCRETESEMI_SOT23-3
Q3: SI1308EDL-T1-GE3; SOT65P210X110-3N
R1, R1_PINH, R1_PINH1, R2-PINH1, R2_PINH, R3, R5, R6, R7, R8, R9, R10: 10K; ESP32_WROVER_EAGLE-LTSPICE_R0402
R1_BAT: 200; ESP32_WROVER_EAGLE-LTSPICE_R0402
R1_PWRUSB: 100K; ESP32_WROVER_EAGLE-LTSPICE_R0402
R2: 2.2; ESP32_WROVER_EAGLE-LTSPICE_R0402
R2-USB: 5k1; ESP32_WROVER_EAGLE-LTSPICE_R0402
R2-USB1: 5K1; ESP32_WROVER_EAGLE-LTSPICE_R0402
R2_BAT: 2K; ESP32_WROVER_EAGLE-LTSPICE_R0402
R4: 0.47; ESP32_WROVER_EAGLE-LTSPICE_R0402
RESET_BUTTON: BUTTON_CUSYOMV1; MYBUTTON
R_BOOT: 10k; ESP32_WROVER_EAGLE-LTSPICE_R0402
R_CAPACITOR: 15; ESP32_WROVER_EAGLE-LTSPICE_R0402
R_CHANGE: 10k; ESP32_WROVER_EAGLE-LTSPICE_R0402
R_CL1: 10K; ESP32_WROVER_EAGLE-LTSPICE_R0402
R_RESET: 10k; ESP32_WROVER_EAGLE-LTSPICE_R0402
SENSOR2: ESP32_WROVER_BME680_BME680; ESP32_WROVER_BME680_PSON80P300X300X100-8N
SJ1: SJ
TP1, TP2, TP3, TP4, TP5, TP6, TP7, TP8, TP9, TP10, TP11, TP12, TP13, TP14, TP15, TP16, TP17: TPTP20R; TP20R
U1: W25Q512JVEIQ; SON127P600X800X80-9N
U2: ESP32-C6-WROOM-1-N8; XCVR_ESP32-C6-WROOM-1-N8
U3: DS3231SN#; SOIC127P1032X265-16N
U4: MAX17048G+T10; SON50P200X200X80-9N

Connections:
3V3: C1_BAT2.1, C3.+, C9.1, D7.2 (ANODE), IC1.2 (VDD), IC4.5 (VOUT), J3.2, J4.P4 (VDD), Q2.3 (D), R1.2, R1_PINH1.2, R2-PINH1.2, R5.2, R6.2, R7.2, R8.2, R9.2, R10.2, R_BOOT.1, R_CHANGE.1, R_CL1.1, R_RESET.1, TP16.TP, U1.3 (!WP!(IO2)), U1.7 (!HOLD!/!RESET!(IO3)), U1.8 (VCC), U2.2 (3V3), U3.2 (VCC)
32KHZ: R2-PINH1.1, U2.9 (IO1), U3.1 (32KHZ)
DN: D1.4 (I/O2_2), J2.A7, J2.B7
DP: D1.6 (I/O1_2), J2.A6, J2.B6
EPD_3V3: C7.1, EPD_C5.1, J1.15, J1.16, L1.2, Q2.2 (S), TP17.TP
EPD_3V3_C: Q2.1 (G), R_CL1.2, TP13.TP, U2.18 (IO20)
EPD_BUSY: J1.9, TP9.TP, U2.26 (IO3)
EPD_CS: D6.2, J1.12, R9.1, TP10.TP, U2.11 (IO10)
EPD_DC: J1.11, TP11.TP, U2.5 (IO5)
EPD_RST: J1.10, TP12.TP, U2.21 (IO23)
FLASH_CS: D9.2, R5.1, U1.1 (!CS), U2.12 (IO11)
GDR: J1.2, Q3.1 (G), R3.1
GND: BOOT_BUTTON.1, BOOT_BUTTON.2, C1.2, C1_BAT.2, C1_BAT1.2, C1_BAT2.2, C2.2, C2_BAT.2, C3.-, C4_USB.2, C5.2, C5_USB.2, C6.2, C7.2, C8.2, C9.2, C10.2, C10_SUPERCAP.1, CHANGE_BUTTON.1, CHANGE_BUTTON.2, C_DELAY.2, D1.2 (GND), D3.2 (K), D6.1, D8.1, D9.1, D10.1, D11.1, D12.1, EPD_C1.2, EPD_C2.2, EPD_C5.2, EPD_C6.2, EPD_C7.2, EPD_C8.2, EPD_C9.2, EPD_C10.2, EPD_C11.2, EPD_C12.2, IC1.3 (GND), IC4.2 (VSS), J1.8, J1.17, J1.MP1, J1.MP2, J2.A1, J2.A12, J2.B1, J2.B12, J2.MP1, J2.MP2, J2.MP3, J2.MP4, J3.1, J4.G1 (GND_1), J4.G2 (GND_2), J4.G3 (GND_3), J4.G4 (GND_4), J4.P6 (VSS), MCP73831.2 (VSS), R1_PWRUSB.1, R2.1, R2-USB.2, R2-USB1.1, R2_BAT.1, R3.2, RESET_BUTTON.1, RESET_BUTTON.2, SENSOR2.1 (GND), SENSOR2.5 (SDO), SENSOR2.7 (GND), SJ1.1, TP4.TP, TP5.TP, U1.4 (GND), U1.9 (EXP), U2.1 (GND), U2.28 (GND), U2.29_1 (GND), U2.29_2 (GND), U2.29_3 (GND), U2.29_4 (GND), U2.29_5 (GND), U2.29_6 (GND), U2.29_7 (GND), U2.29_8 (GND), U2.29_9 (GND), U3.13 (GND), U4.1 (CTG), U4.4 (GND), U4.6 (QSTRT), U4.9 (EP)
GPIO8: R1.1, U2.10 (IO8)
I2C_PW: C1.1, C2.1, R1_PINH.2, R2_PINH.2, SENSOR2.2 (CSB), SENSOR2.6 (VDDIO), SENSOR2.8 (VDD), U2.17 (IO19)
INT_RTC: R1_PINH1.1, TP15.TP, U2.8 (IO0), U3.3 (SQW/!INT)
IO/BOOT: BOOT_BUTTON.3, BOOT_BUTTON.4, C6.1, R_BOOT.2, U2.15 (IO9)
IO/CHANGE: C10.1, CHANGE_BUTTON.3, CHANGE_BUTTON.4, R_CHANGE.2, U2.23 (IO15)
MISO: D12.2, J4.P7 (DAT0), R8.1, TP6.TP, U1.2 (DO(IO1)), U2.27 (IO2)
MOSI: D11.2, J1.14, J4.P3 (CMD), R7.1, TP7.TP, U1.5 (DI(IO0)), U2.7 (IO7)
unnamed: J2.B5, R2-USB.1
unnamed: EPD_C12.1, J1.24
unnamed: J2.A5, R2-USB1.2
unnamed: C1_BAT1.1, D2.1 (CATHODE), IC4.1 (VIN), IC4.3 (CE), Q1.2 (S)
unnamed: MCP73831.1 (STAT), R1_BAT.1
unnamed: CHG_LED.C, R1_BAT.2
unnamed: C4.1, D3.1 (A), D4.2 (K)
unnamed: EPD_C6.1, J1.18
unnamed: MCP73831.5 (PROG), R2_BAT.2
unnamed: EPD_C1.1, J1.4
unnamed: EPD_C2.1, J1.5
unnamed: C_DELAY.1, IC1.5 (CT)
unnamed: EPD_C7.1, J1.19
unnamed: EPD_C8.1, J1.20
unnamed: EPD_C10.1, J1.22
unnamed: D7.1 (CATHODE), R_CAPACITOR.2
PREVGH: D5.2 (K), EPD_C9.1, J1.21
PREVGL: D4.1 (A), EPD_C11.1, J1.23
RESE: J1.3, Q3.2 (S), R4.1
RESE': R2.2, R4.2, SJ1.2
RESET: C5.1, IC1.1 (VOUT), RESET_BUTTON.3, RESET_BUTTON.4, R_RESET.2, U2.3 (EN)
RTC_RST: U2.16 (IO18), U3.4 (!RST)
RX: TP2.TP, U2.24 (RXD0/GPIO17)
SCK: D10.2, J1.13, J4.P5 (CLK), R6.1, TP8.TP, U1.6 (CLK), U2.6 (IO6)
SCL: J3.4, R2_PINH.1, SENSOR2.4 (SCK), U2.20 (IO22), U3.16 (SCL), U4.7 (SCL)
SDA: J3.3, R1_PINH.1, SENSOR2.3 (SDI), U2.19 (IO21), U3.15 (SDA), U4.8 (SDA)
SRC: C4.2, D5.1 (A), L1.1, Q3.3 (D)
SS_SD: D8.2, J4.P2 (CD/DAT3), R10.1, U2.4 (IO4)
TX: TP1.TP, U2.25 (TXD0/GPIO16)
USB_D+: D1.1 (I/O1_1), U2.14 (IO13)
USB_D-: D1.3 (I/O2_1), U2.13 (IO12)
VBAT: C2_BAT.1, MCP73831.3 (VBAT), Q1.3 (D), TP3.TP, U4.2 (CELL), U4.3 (VDD)
VBUS: C1_BAT.1, C4_USB.1, C5_USB.1, CHG_LED.A, D1.5 (VBUS), D2.2 (ANODE), MCP73831.4 (VIN), PFMP.050.1.2, Q1.1 (G), R1_PWRUSB.2, TP14.TP
VRTC: C8.1, C10_SUPERCAP.2, R_CAPACITOR.1, U3.14 (VBAT)
VUSB: J2.A4, J2.A9, J2.B4, J2.B9, PFMP.050.1.1

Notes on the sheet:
USB C connector & ESD protection
SD Card
LDO Voltage Regulator
Display Type Selector
E-Paper Drive Circuit
Li-Po Battery Charging Controller
ESP32 C6
E-Paper Display Header
EPD Power
Environmental Sensor BME688
Voltage Supervisor + Reset & Boot / IO Button
Battery ChargeLevel
RTC Module DS3231SN
Test Pads
Qwiic / Stemma QT
SPI ESD Protection Lines
External NORFlash64MB
DMG2305UX-7

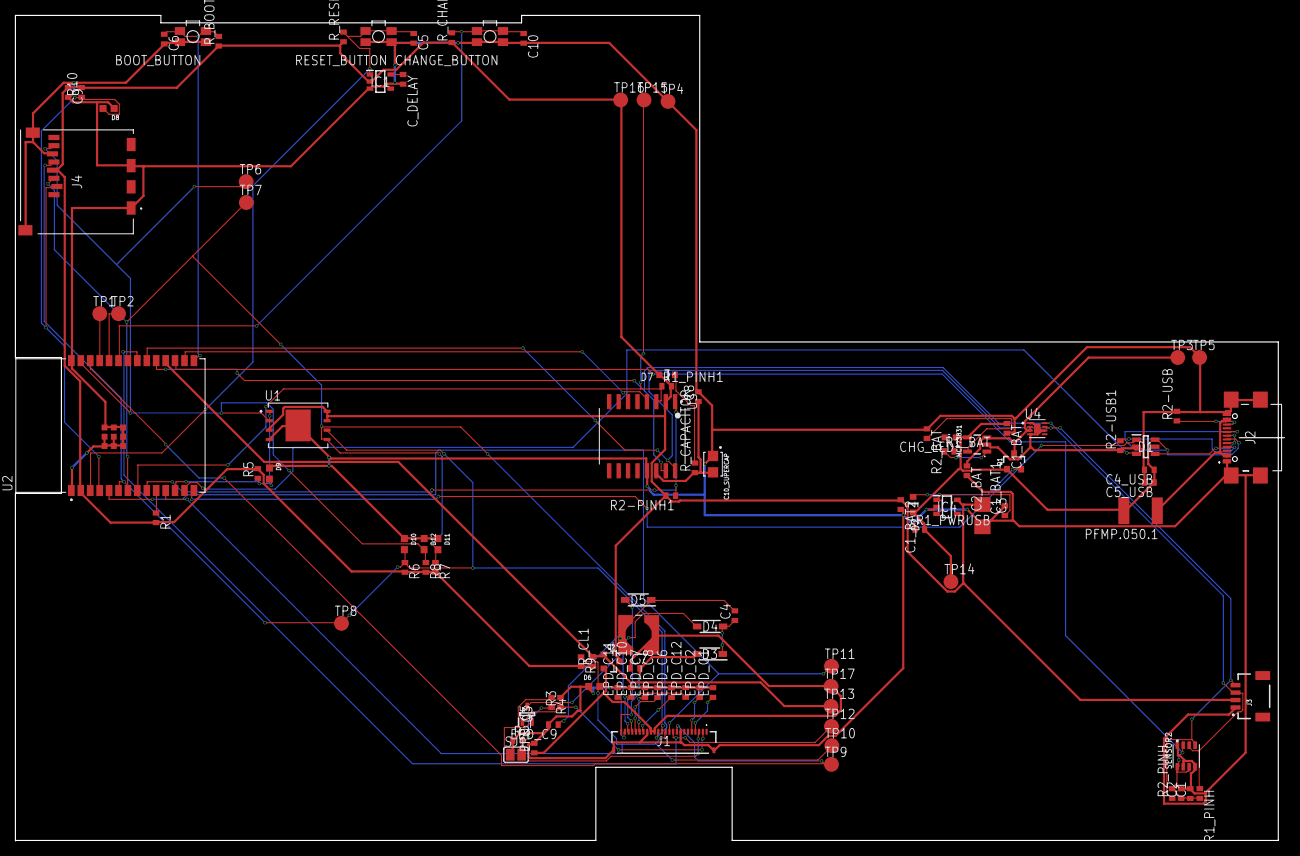
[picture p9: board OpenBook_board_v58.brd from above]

Board: 2 copper layers, 171.0 x 111.2 mm, 103 parts (0 on the bottom side), 55 nets.

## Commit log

2025-03-19 Added the schematic file for the e-book reader
2025-04-06 Added images for the device
2025-04-06 Added Schematic(.sch) as well as Board(.brd)
    [Proiect-Open-Book.brd]
2025-04-06 Finised both 3D files
    [BOOM.csv, Pick and Place.csv]
2025-04-06 Gerbers, BOM and Pick_and_Place done
2025-04-14 Replaced board and schematic with the correct ones.
    [OpenBook_board.brd, OpenBook_schematic.sch]
2025-04-14 Added rendered photos of battery and display
2025-04-14 Added rendered images for battery and display
2025-04-15 Final brd
    [OpenBook_board_v58.brd]

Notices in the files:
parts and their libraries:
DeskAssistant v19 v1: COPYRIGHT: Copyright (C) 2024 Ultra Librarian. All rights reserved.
